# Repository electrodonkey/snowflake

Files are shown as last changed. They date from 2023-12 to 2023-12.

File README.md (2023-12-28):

# snowflake

RF controlled Christmas decoration

## architecture

- MCU: TI MSPM0L1306
- LED DRIVER: TI LP5569
- SUB-GHz: ST S2-LP
- POWER: CR2032

## hardware
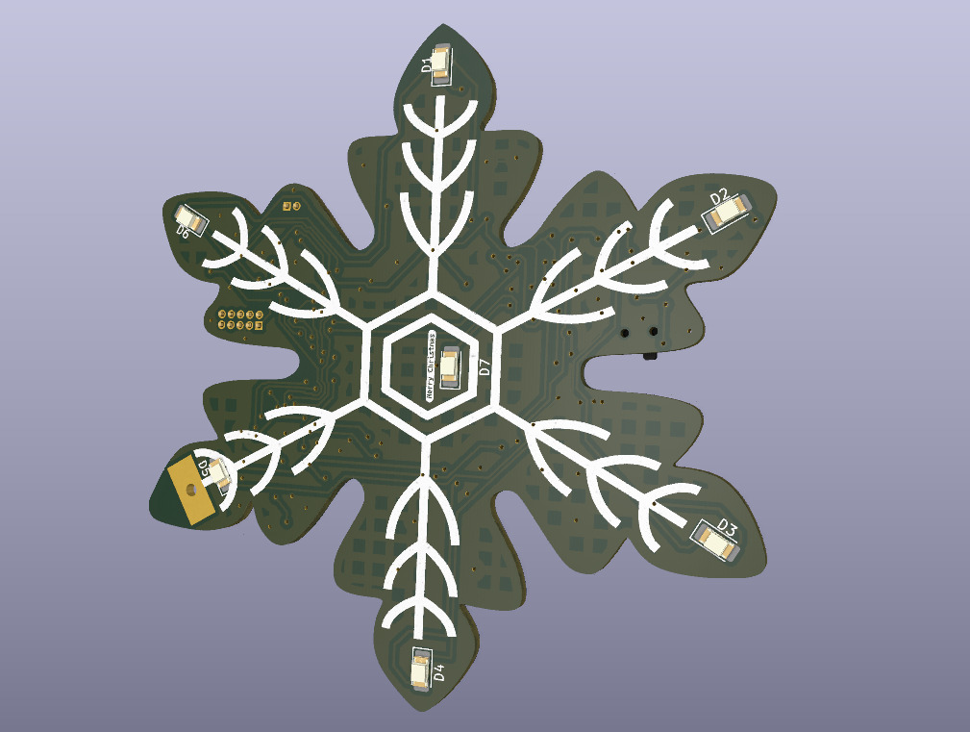
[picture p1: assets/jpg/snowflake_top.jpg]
PCB Snowflake TOP Snowflake TOP

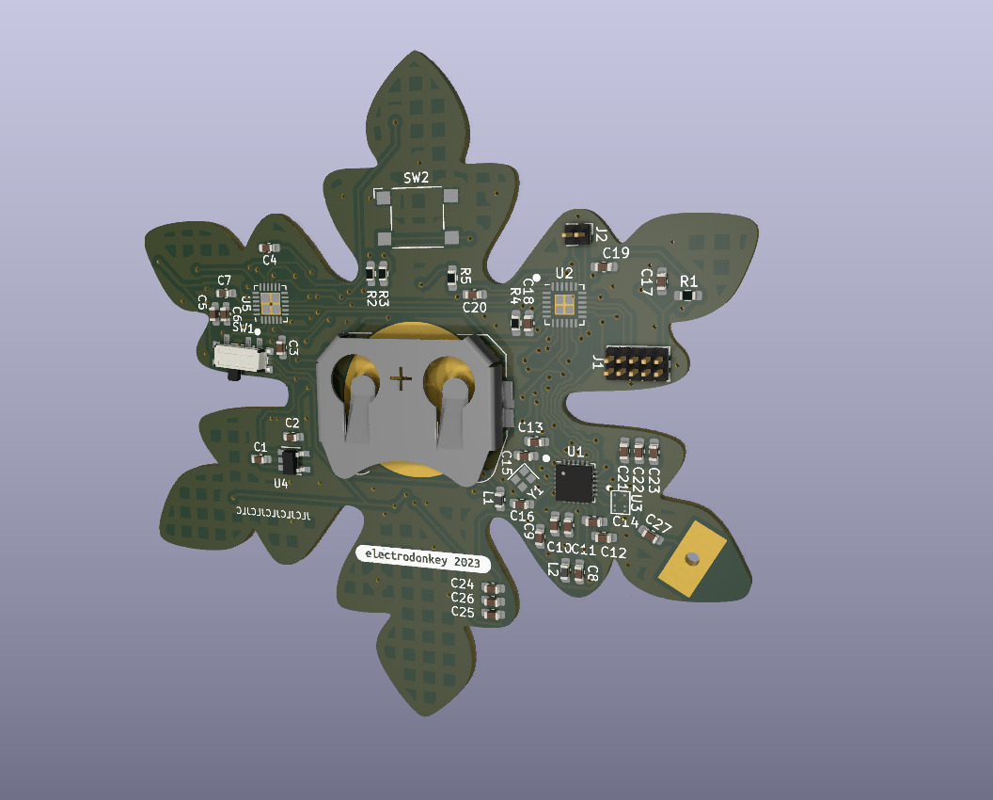
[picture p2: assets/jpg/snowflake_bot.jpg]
PCB Snowflake BOTTOM Snowflake BOTTOM


PCB Snowflake Schematic Snowflake Schematics

[schematic pdf](hardware/output/snowflake.pdf)

## licence

Copyright 2023 Dan Chirciu (electrodonkey)

Permission is hereby granted, free of charge, to any person obtaining a copy of this software and associated documentation files (the “Software”), to deal in the Software without restriction, including without limitation the rights to use, copy, modify, merge, publish, distribute, sublicense, and/or sell copies of the Software, and to permit persons to whom the Software is furnished to do so, subject to the following conditions:

The above copyright notice and this permission notice shall be included in all copies or substantial portions of the Software.

THE SOFTWARE IS PROVIDED “AS IS”, WITHOUT WARRANTY OF ANY KIND, EXPRESS OR IMPLIED, INCLUDING BUT NOT LIMITED TO THE WARRANTIES OF MERCHANTABILITY, FITNESS FOR A PARTICULAR PURPOSE AND NONINFRINGEMENT. IN NO EVENT SHALL THE AUTHORS OR COPYRIGHT HOLDERS BE LIABLE FOR ANY CLAIM, DAMAGES OR OTHER LIABILITY, WHETHER IN AN ACTION OF CONTRACT, TORT OR OTHERWISE, ARISING FROM, OUT OF OR IN CONNECTION WITH THE SOFTWARE OR THE USE OR OTHER DEALINGS IN THE SOFTWARE.

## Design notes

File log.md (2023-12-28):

# Abstract
This project is a small wireless Christmas decoration that can be coupled in a network of snowflakes. It is based on the TI MSPM0L1306 microcontroller and the ST S2-LP sub-GHz transceiver.

# Inspiration 
- [Kingpin DEFCON 27 badge](http://www.grandideastudio.com/wp-content/uploads/dc27_bdg_schematic.pdf)

# Parts and documentation
- CPU - TI MSPM0L1306
  - [Datasheet](https://www.ti.com/lit/ds/symlink/mspm0l1306.pdf)
  - 24 PIN RGE Package (VQFN)
  - cost: 1.5$
- Sub-GHz transceiver - ST S2-LP
  - Local regulations specify 868MHz band
  - [Datasheet](https://www.st.com/resource/en/datasheet/s2-lp.pdf)
  - 24 PIN RGE Package (VQFN)
  - cost: 1.5$
- Integrated balun - ST BALF-SPI2-01D3
  - [Datasheet](https://ro.mouser.com/datasheet/2/389/balf_spi2_01d3-1848836.pdf)
  - flip chip 6 bump package
  - cost: 0.5$
- LED Driver - LP5569
    - [Datasheet](https://www.ti.com/lit/ds/symlink/lp5569.pdf)
    - 24 PIN RGE Package (VQFN)
    - cost: 1.5$
- LDO 1.8V - LD56020M180R
  - [Datasheet](https://ro.mouser.com/datasheet/2/389/ld56020-2935645.pdf)
  - 6 PIN SOT-23 Package
  - cost: 0.1$
- Supply via CR2032 battery (3V@250mAh)
  - cost : 0.5$
- 6 x 1206 LEDs green
  - [Datasheet](https://ro.mouser.com/datasheet/2/216/APTR3216ZGCK-1602205.pdf)
  - cost: [0.21$/piece @ 100 pcs](https://ro.mouser.com/ProductDetail/Kingbright/APTR3216ZGCK?qs=Oo40KB9lBTkC8CPC9zcCIg%3D%3D)
- Antenna
  - [Datasheet](https://eu.mouser.com/datasheet/2/418/9/ENG_DS_ANT_418_HETH_A-3237771.pdf)
  - cost: 1.5$
# Costs
- PCB: 5$
- Components: 7$
- Total: 12$

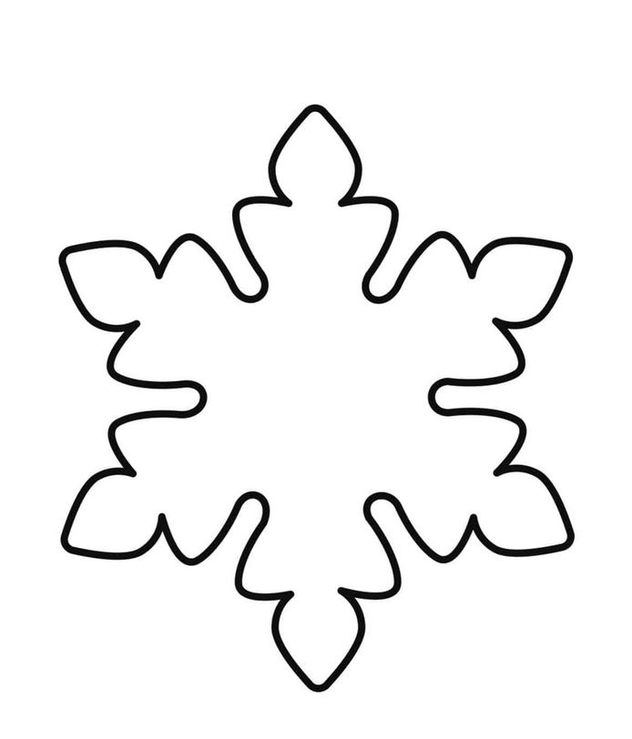
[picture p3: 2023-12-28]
assets/snowflake_inspiration.JPG

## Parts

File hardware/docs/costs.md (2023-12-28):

# costs of components
# -------------------
# table

# | component | cost | source | notes |
# | --------- | ---- | ------ | ----- |
# | MSPM0L1306 | 1.5$ | [TI](https://www.ti.com/lit/ds/symlink/mspm0l1306.pdf) | 24 PIN RGE Package (VQFN) |
# | S2-LP | 1.5$ | [ST](https://www.st.com/resource/en/datasheet/s2-lp.pdf) | 24 PIN RGE Package (VQFN) |
# | BALF-SPI2-01D3 | 0.5$ | [ST](https://ro.mouser.com/datasheet/2/389/balf_spi2_01d3-1848836.pdf) | flip chip 6 bump package |
STM32G030F6P6TR	10	$0.97	$9.70
LD56020M180R	10	$0.55	$5.50
S2-LPQTR	6	$3.41	$20.46

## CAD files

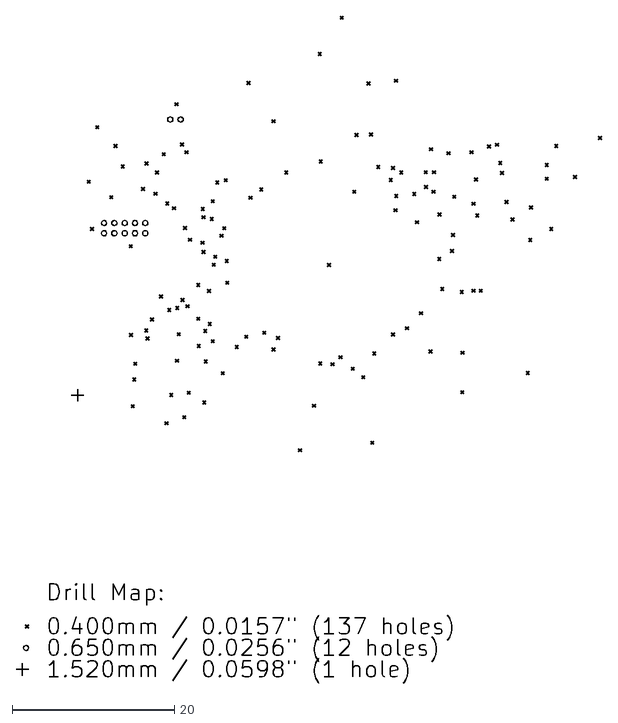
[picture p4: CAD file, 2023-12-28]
hardware/output/snowflake-PTH-drl_map.dxf
72.1 x 82.1

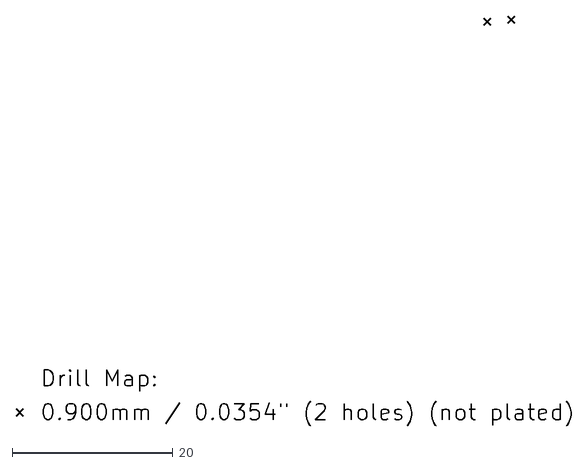
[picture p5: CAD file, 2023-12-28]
hardware/output/snowflake-NPTH-drl_map.dxf
69.0 x 51.0

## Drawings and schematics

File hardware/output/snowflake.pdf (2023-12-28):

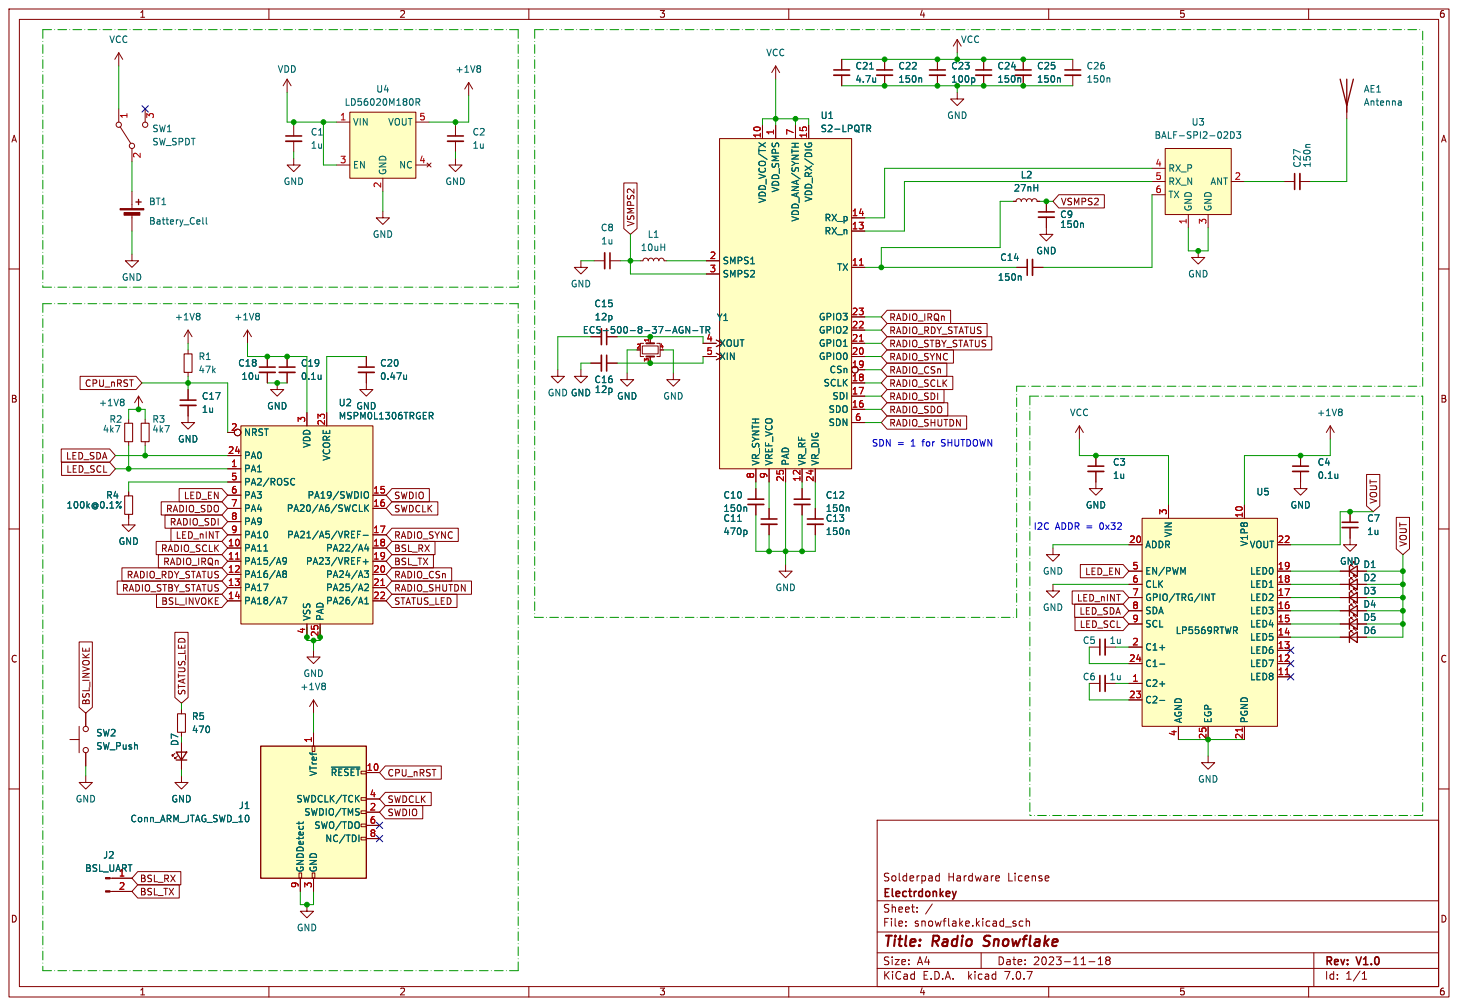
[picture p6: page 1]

1 VDD_VCO/TX 10 TX 11 VR_RF 12 RX_n 13 RX_p 14 VDD_RX/DIG 15 SDO 16 SDI 17 SCLK 18 CSn 19 SMPS1 2 GPIO0 20 GPIO1 21 GPIO2 22 GPIO3 23 VR_DIG 24 PAD 25 SMPS2 3 XOUT 4 XIN 5 SDN 6 VDD_ANA/SYNTH

4 EN/PWM 5 CLK 6 GPIO/TRG/INT 7 SDA 8 SCL 9 U5

4 EN/PWM 5 CLK 6 GPIO/TRG/INT 7 SDA 8 SCL 9 C7

3 SWDCLK/TCK 4 SWO/TDO 6 NC/TDI 8 GNDDetect 9 GND

3 SWDCLK/TCK 4 SWO/TDO 6 NC/TDI 8 GNDDetect 9

File: snowflake.kicad_sch Sheet: / Electrdonkey

Id: 1/1 Title: Radio Snowflake

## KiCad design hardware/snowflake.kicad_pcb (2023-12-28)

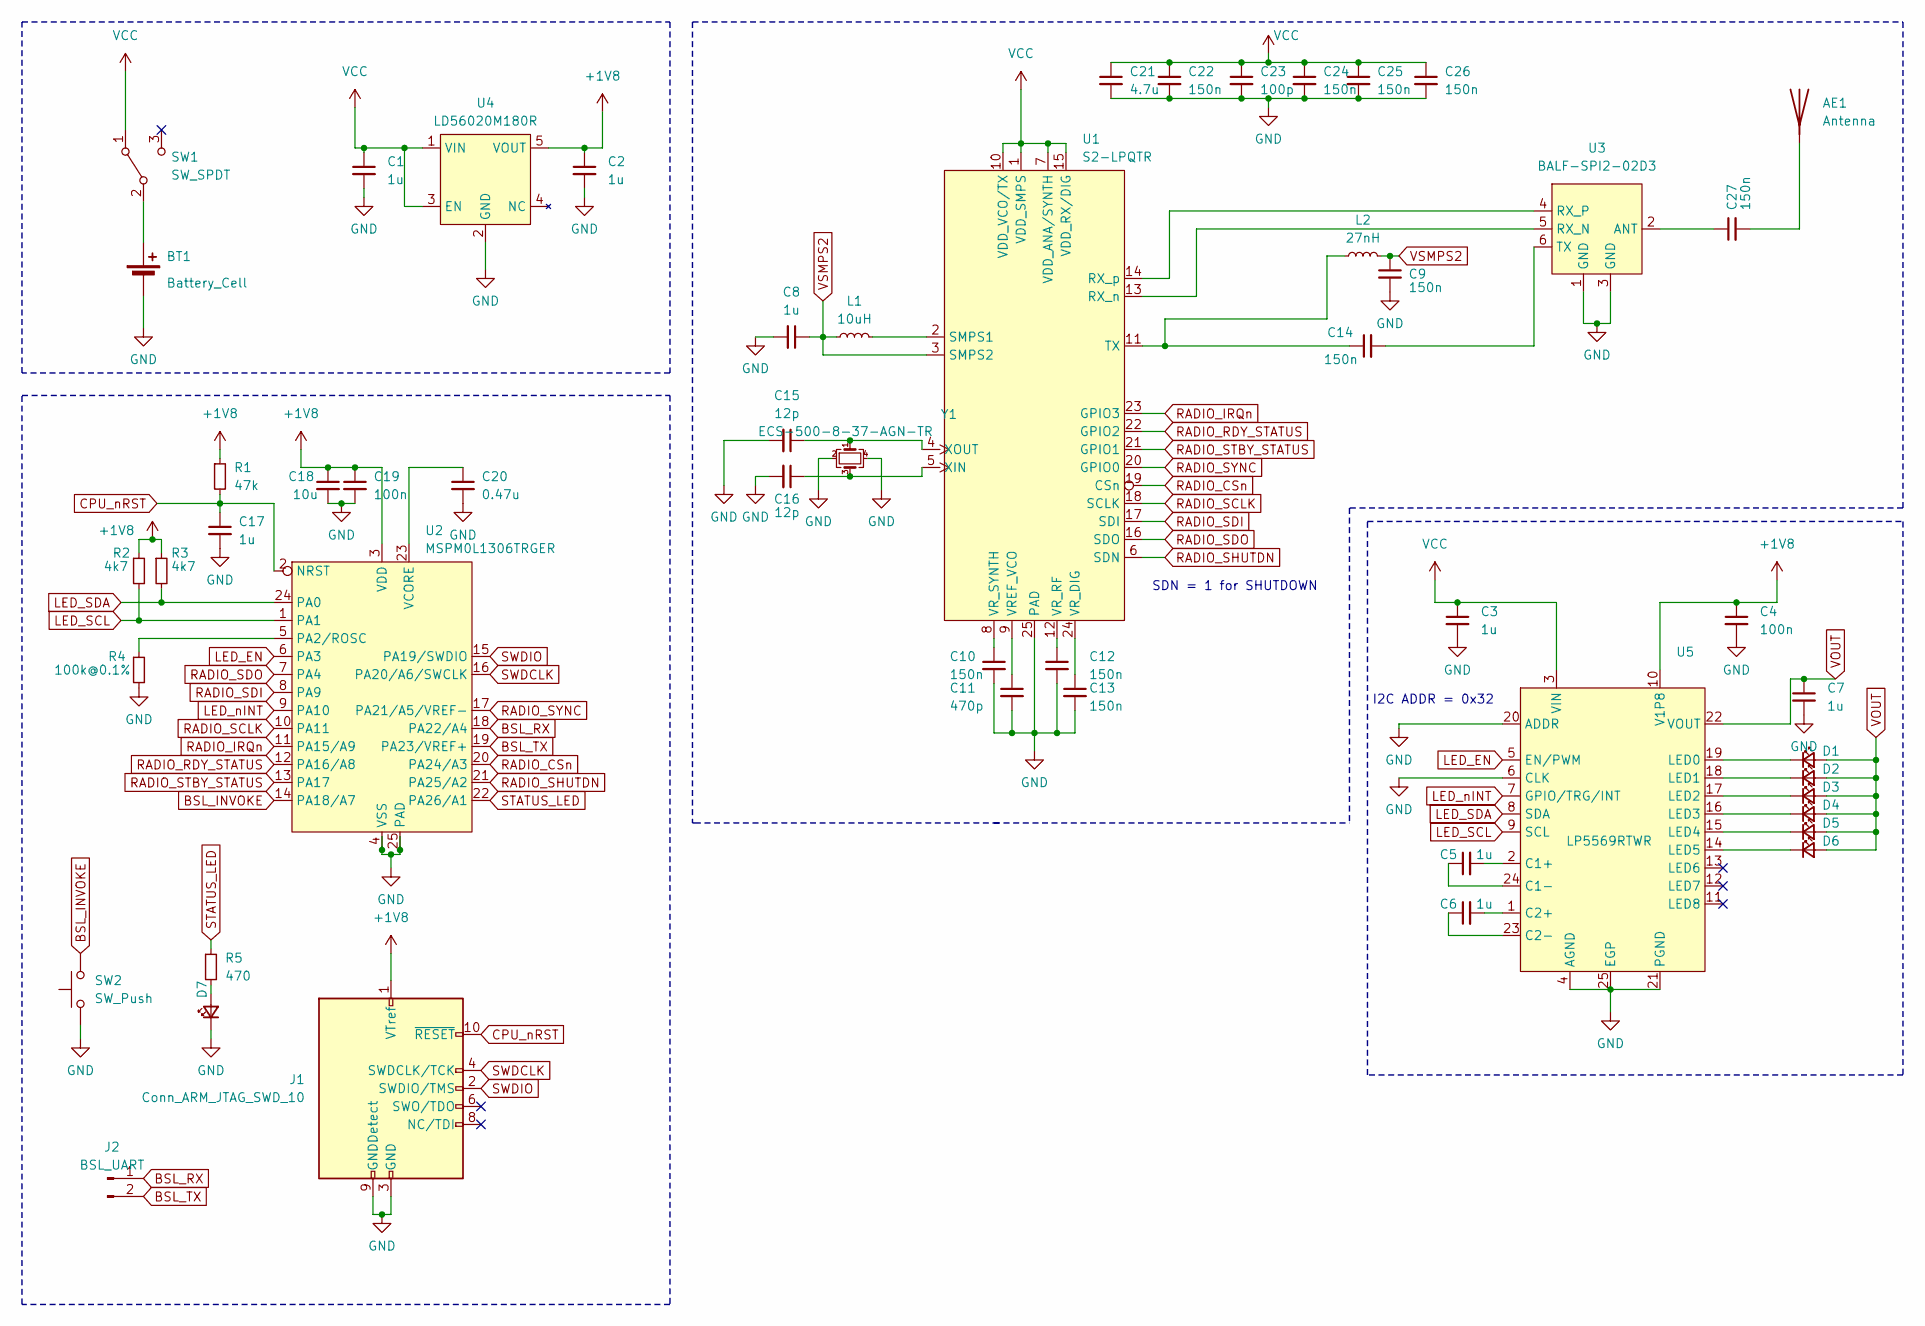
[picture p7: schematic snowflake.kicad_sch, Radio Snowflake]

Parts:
AE1: Antenna; ANT-418-HETH
BT1: Battery_Cell; BatteryHolder_Keystone_3034_1x20mm
C1, C2, C3, C5, C6, C7, C8, C17: 1u; C_0603_1608Metric_Pad1.08x0.95mm_HandSolder
C4, C19: 100n; C_0603_1608Metric_Pad1.08x0.95mm_HandSolder
C9, C10, C12, C13, C14, C22, C24, C25, C26, C27: 150n; C_0603_1608Metric_Pad1.08x0.95mm_HandSolder
C11: 470p; C_0603_1608Metric_Pad1.08x0.95mm_HandSolder
C15, C16: 12p; C_0603_1608Metric_Pad1.08x0.95mm_HandSolder
C18: 10u; C_0603_1608Metric_Pad1.08x0.95mm_HandSolder
C20: 0.47u; C_0603_1608Metric_Pad1.08x0.95mm_HandSolder
C21: 4.7u; C_0603_1608Metric_Pad1.08x0.95mm_HandSolder
C23: 100p; C_0603_1608Metric_Pad1.08x0.95mm_HandSolder
D1, D2, D3, D4, D5, D6, D7: LED; LED_1206_3216Metric_Pad1.42x1.75mm_HandSolder
J1: Conn_ARM_JTAG_SWD_10; PinHeader_2x05_P1.27mm_Vertical
J2: BSL_UART; PinHeader_1x02_P1.27mm_Vertical
L1: 10uH; L_0603_1608Metric_Pad1.05x0.95mm_HandSolder
L2: 27nH; L_0603_1608Metric_Pad1.05x0.95mm_HandSolder
R1: 47k; R_0603_1608Metric_Pad0.98x0.95mm_HandSolder
R2, R3: 4k7; R_0603_1608Metric_Pad0.98x0.95mm_HandSolder
R4: 100k@0.1%; R_0603_1608Metric_Pad0.98x0.95mm_HandSolder
R5: 470; R_0603_1608Metric_Pad0.98x0.95mm_HandSolder
SW1: SW_SPDT; SW_SPDT_PCM12
SW2: SW_Push; SW_SPST_Omron_B3FS-100xP
U1: S2-LPQTR; QFN-24-1EP_4x4mm_P0.5mm_EP2.7x2.7mm
U2: MSPM0L1306TRGER; Texas_RGE0024C_EP2.1x2.1mm
U3: BALF-SPI2-02D3; balf-spi2-01d3
U4: LD56020M180R; SOT-23-5_HandSoldering
U5: LP5569RTWR; WQFN-24-1EP_4x4mm_P0.5mm_EP2.6x2.6mm
Y1: ECS-500-8-37-AGN-TR; Crystal_SMD_2016-4Pin_2.0x1.6mm

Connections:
+1V8: C2.1, C4.1, C18.1, C19.1, J1.1 (VTref), R1.1, R2.1, R3.1, U2.3 (VDD), U4.5 (VOUT), U5.10 (V1P8)
BSL_INVOKE: SW2.2, U2.14 (PA18/A7)
BSL_RX: J2.1, U2.18 (PA22/A4)
BSL_TX: J2.2, U2.19 (PA23/VREF+)
CPU_nRST: C17.1, J1.10 (~RESET), R1.2, U2.2 (NRST)
GND: BT1.2 (-), C1.2, C2.2, C3.2, C4.2, C7.2, C8.2, C9.2, C10.2, C11.2, C12.2, C13.2, C15.2, C16.2, C17.2, C18.2, C19.2, C20.2, C21.2, C22.2, C23.2, C24.2, C25.2, C26.2, D7.1 (K), J1.3 (GND), J1.5 (GND), J1.9 (GNDDetect), R4.2, SW2.1, U1.25 (PAD), U2.4 (VSS), U2.25 (PAD), U3.1 (GND), U3.3 (GND), U4.2 (GND), U5.4 (AGND), U5.6 (CLK), U5.20 (ADDR), U5.21 (PGND), U5.25 (EGP), Y1.2, Y1.4
LED_EN: U2.6 (PA3), U5.5 (EN/PWM)
LED_SCL: R2.2, U2.1 (PA1), U5.9 (SCL)
LED_SDA: R3.2, U2.24 (PA0), U5.8 (SDA)
LED_nINT: U2.9 (PA10), U5.7 (GPIO/TRG/INT)
unnamed: AE1.1 (A), C27.2
unnamed: BT1.1 (+), SW1.2 (B)
unnamed: D1.1 (K), U5.19 (LED0)
unnamed: D2.1 (K), U5.18 (LED1)
unnamed: D3.1 (K), U5.17 (LED2)
unnamed: D4.1 (K), U5.16 (LED3)
unnamed: D5.1 (K), U5.15 (LED4)
unnamed: D6.1 (K), U5.14 (LED5)
unnamed: D7.2 (A), R5.2
unnamed: U1.13 (RX_n), U3.5 (RX_N)
unnamed: U1.14 (RX_p), U3.4 (RX_P)
unnamed: L1.2, U1.2 (SMPS1)
unnamed: C14.1, L2.1, U1.11 (TX)
unnamed: C11.1, U1.9 (VREF_VCO)
unnamed: C13.1, U1.24 (VR_DIG)
unnamed: C12.1, U1.12 (VR_RF)
unnamed: C10.1, U1.8 (VR_SYNTH)
unnamed: C16.1, U1.5 (XIN), Y1.3
unnamed: C15.1, U1.4 (XOUT), Y1.1
unnamed: R4.1, U2.5 (PA2/ROSC)
unnamed: C20.1, U2.23 (VCORE)
unnamed: C27.1, U3.2 (ANT)
unnamed: C14.2, U3.6 (TX)
unnamed: C5.2, U5.2 (C1+)
unnamed: C5.1, U5.24 (C1-)
unnamed: C6.2, U5.1 (C2+)
unnamed: C6.1, U5.23 (C2-)
RADIO_CSn: U1.19 (CSn), U2.20 (PA24/A3)
RADIO_IRQn: U1.23 (GPIO3), U2.11 (PA15/A9)
RADIO_RDY_STATUS: U1.22 (GPIO2), U2.12 (PA16/A8)
RADIO_SCLK: U1.18 (SCLK), U2.10 (PA11)
RADIO_SDI: U1.17 (SDI), U2.8 (PA9)
RADIO_SDO: U1.16 (SDO), U2.7 (PA4)
RADIO_SHUTDN: U1.6 (SDN), U2.21 (PA25/A2)
RADIO_STBY_STATUS: U1.21 (GPIO1), U2.13 (PA17)
RADIO_SYNC: U1.20 (GPIO0), U2.17 (PA21/A5/VREF-)
STATUS_LED: R5.1, U2.22 (PA26/A1)
SWDCLK: J1.4 (SWDCLK/TCK), U2.16 (PA20/A6/SWCLK)
SWDIO: J1.2 (SWDIO/TMS), U2.15 (PA19/SWDIO)
VCC: C1.1, C3.1, C21.1, C22.1, C23.1, C24.1, C25.1, C26.1, SW1.1 (A), U1.1 (VDD_SMPS), U1.7 (VDD_ANA/SYNTH), U1.10 (VDD_VCO/TX), U1.15 (VDD_RX/DIG), U4.1 (VIN), U4.3 (EN), U5.3 (VIN)
VOUT: C7.1, D1.2 (A), D2.2 (A), D3.2 (A), D4.2 (A), D5.2 (A), D6.2 (A), U5.22 (VOUT)
VSMPS2: C8.1, C9.1, L1.1, L2.2, U1.3 (SMPS2)

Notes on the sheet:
I2C ADDR = 0x32
SDN = 1 for SHUTDOWN

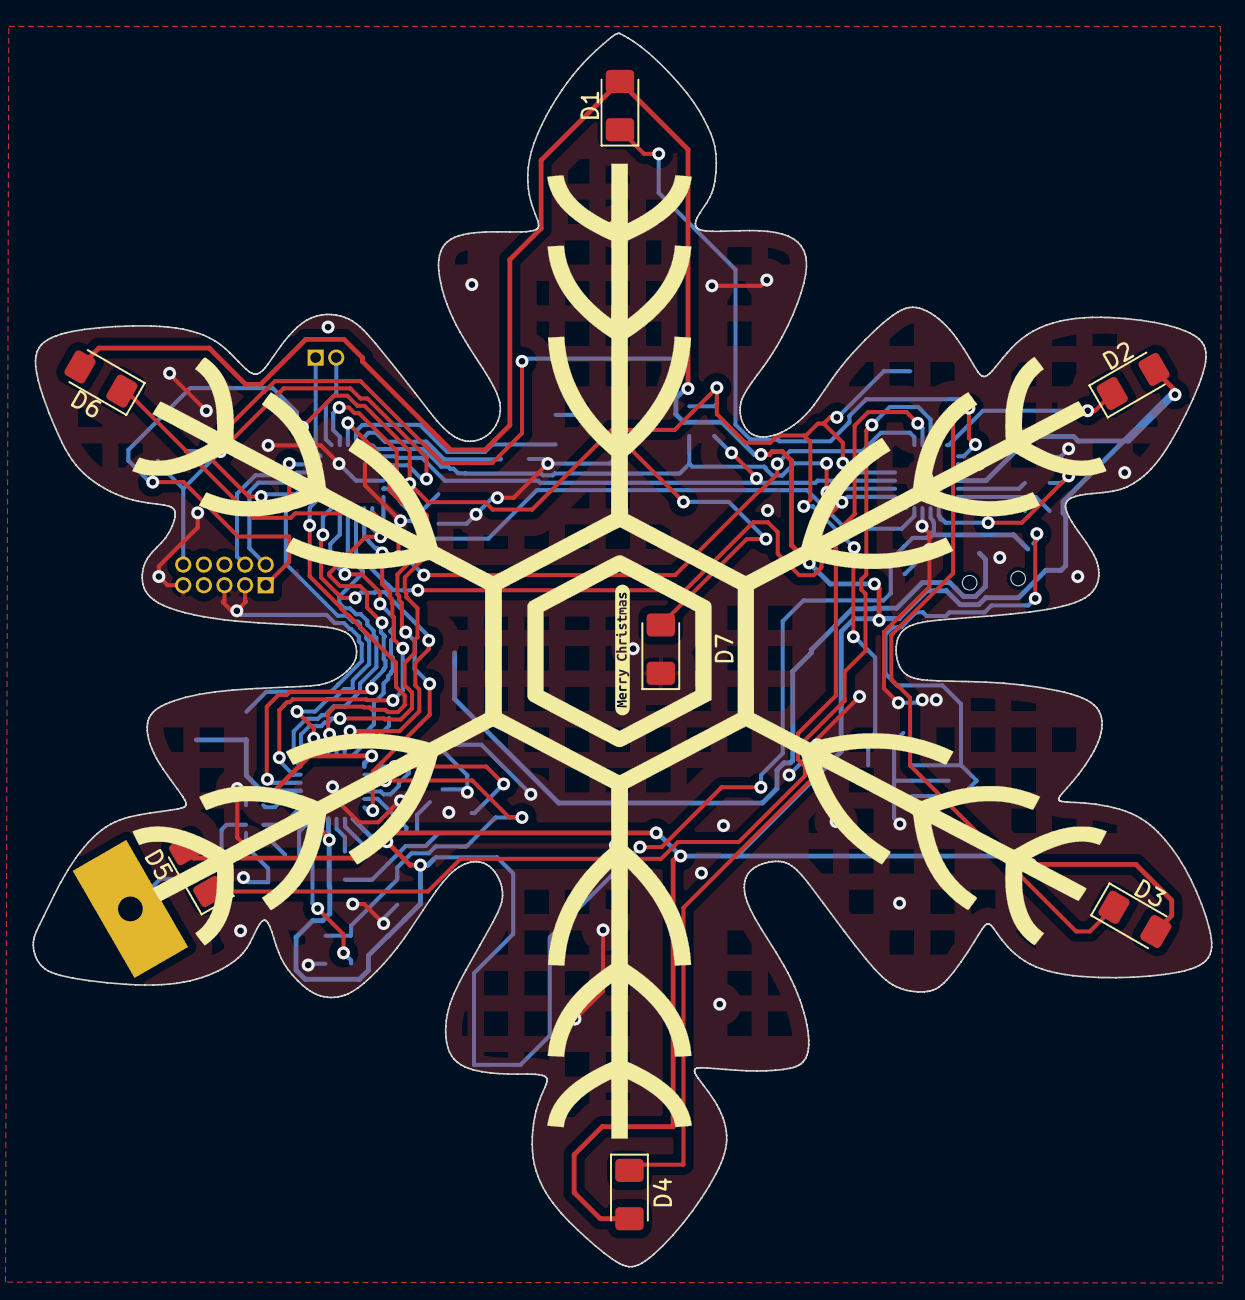
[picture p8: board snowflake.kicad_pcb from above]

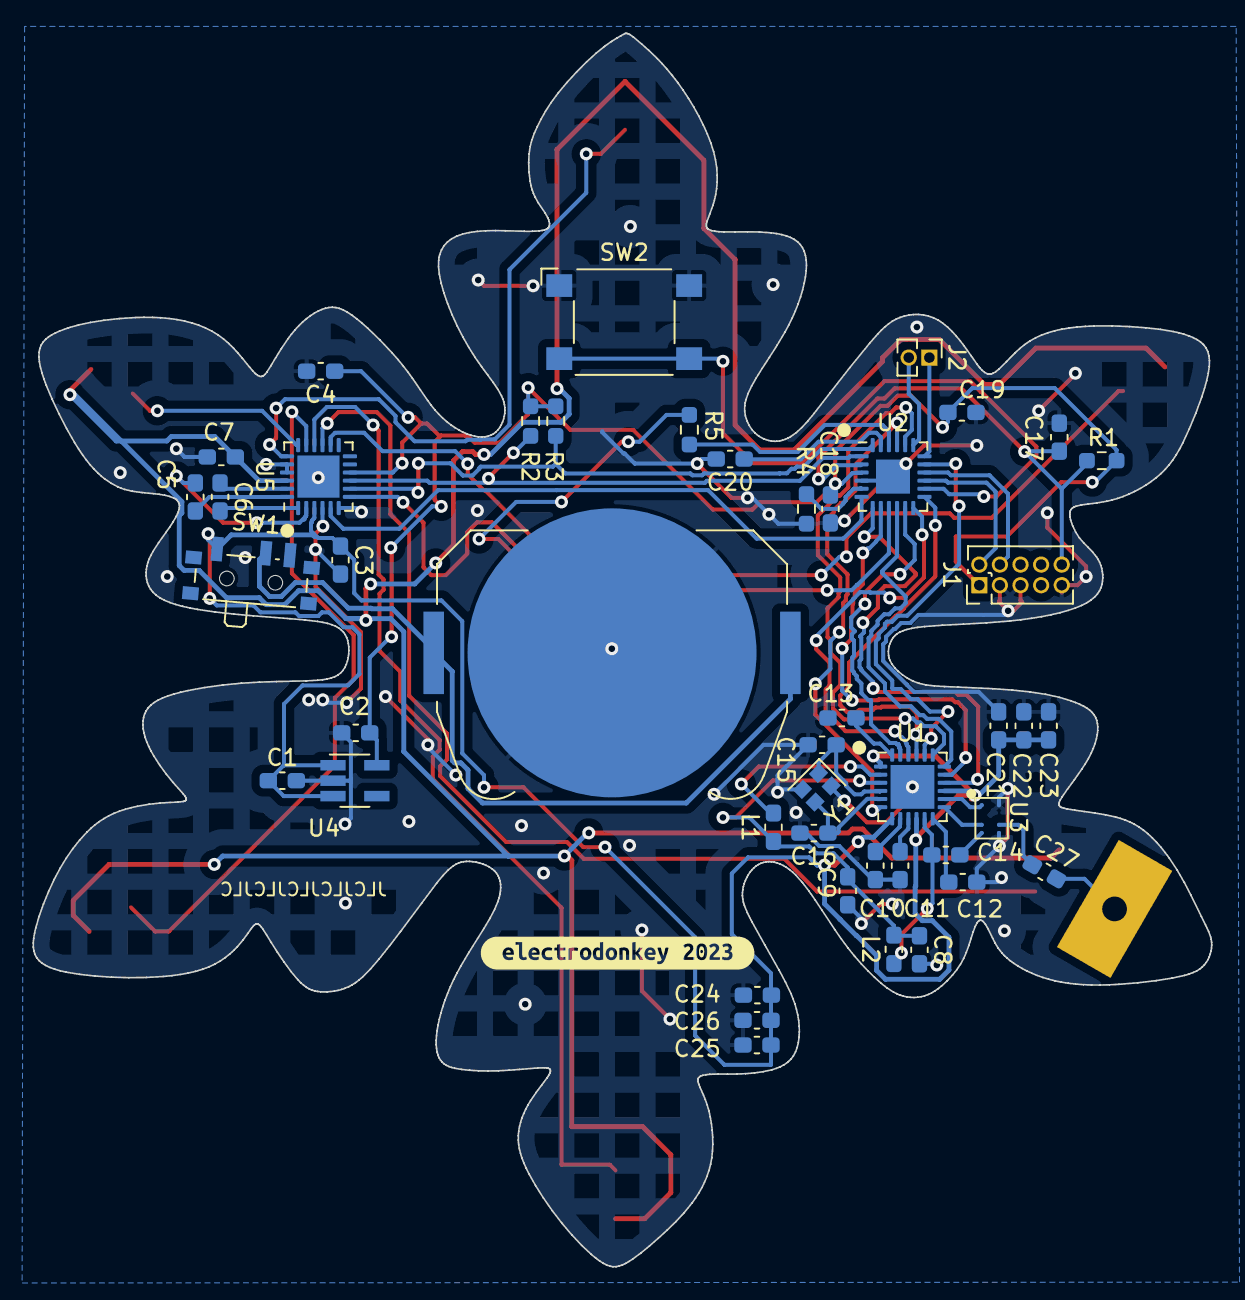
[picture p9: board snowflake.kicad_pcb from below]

Board: 2 copper layers, 72.6 x 76.0 mm, 56 parts (47 on the bottom side), 52 nets.

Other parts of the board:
Ref**: Val**; snowflake_man
kibuzzard-65665C77: G***; kibuzzard-65665C77
kibuzzard-65665DDA: G***; kibuzzard-65665DDA

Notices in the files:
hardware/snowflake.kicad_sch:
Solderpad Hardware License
